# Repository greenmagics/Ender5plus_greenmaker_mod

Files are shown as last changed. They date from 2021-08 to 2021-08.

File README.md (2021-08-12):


# Ender5plus GreenMaker MOD by GreenMagic
Oto mój projekt drukarki 3D opartej na Ender 5 plus.
Lista zmian względem oryginalnej konstrukcji:

  - Kółka Vslot zostały zamienione na prowadnice liniowe MGN12 (2x oś X, 2x oś Y)
  - Bowden zmieniono na BMG direct drive
  - Hotend V6
  - Nadmuch wentylatorem 5015
  - Dodano napinacze pasków
  - Cała karetka osi X aluminiowa
 
Najważniejszą zmianą z tych wszystkich jest wykorzystanie prowadnic liniowych MGN12, które zapewniają sztywność przy dużych prędkościach.
Z powodzeniem od roku używam poprzedniej wersji tego projektu, która wykorzystywała jedną prowadnicę liniową na osi X.
Niewielki luz, który jest potrzebny do poprawnej pracy wózka liniowego powodował wibracje stosunkowo ciężkiego napędu direct i drgania.
Zastosowanie dwóch prowadnic liniowych z obu stron profila 2020 wraz z systemem kasowania luzu rozwiązuje ten problem.




# Oto schemat części, które zostały zmienione względem oryginału:
(Nie licząc napędu osi Y, który został niezmieniony oraz profilu Vslot osi X)



# TODO:
  * Zaprojektować dyszę nadmuchu chłodzącego wydruk (tutaj bardzo bym prosił o pomoc :) )
  * Dodać mocowania końców paska do karetki
  * Dodać model 3D dystansu 5mm pomiędzy BLtouch a jego mocowanie
  * Dodać listę części
  * Dodać rysunki techniczne elementów do wycięcia z aluminium
  * Dodać pliki STL modeli do druku
  * Zaokrąglić krawędzie modeli

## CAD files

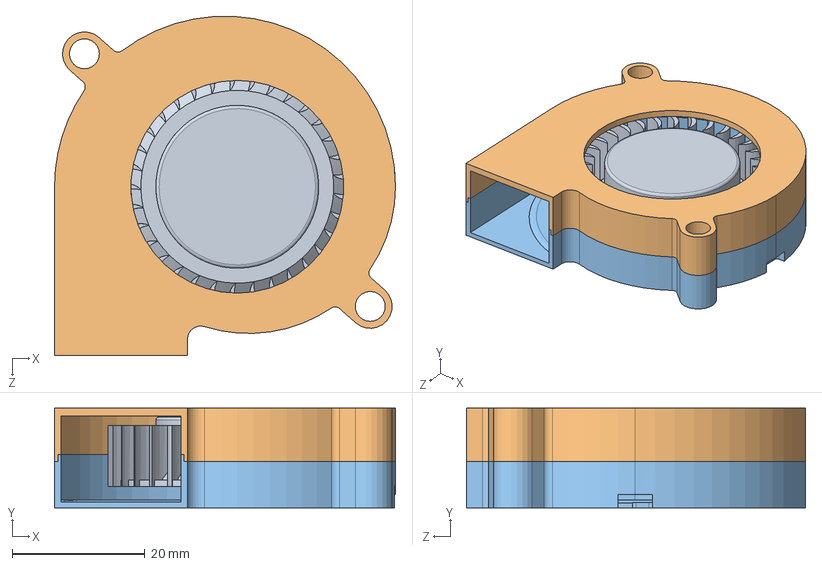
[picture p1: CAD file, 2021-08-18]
czesci_dodane/direct/Radial-Cooling-Fan-5015-DC12V v3.SLDASM
51.3 x 15.0 x 51.0 mm
turbine.stp
top.stp
bottom.stp

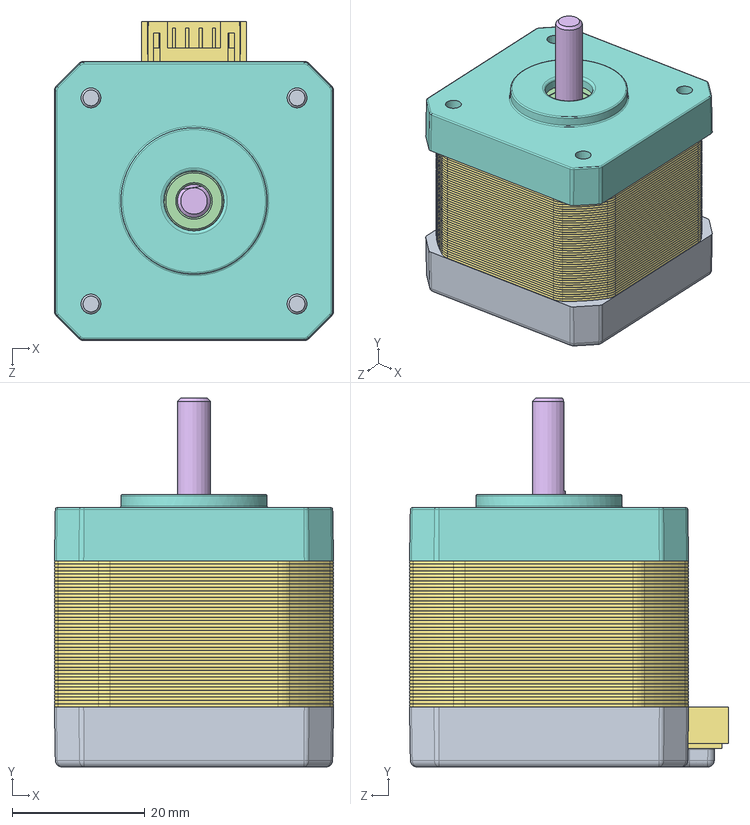
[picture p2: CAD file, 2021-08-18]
czesci_dodane/nema17/Nema17.SLDASM
42.0 x 55.5 x 48.0 mm
Bottom_cap
Protective_film_bottom
Bearing_spring
Bearing x 2
Thick_washer x 2
Rotor
Stator
Top_cap
Screw x 4

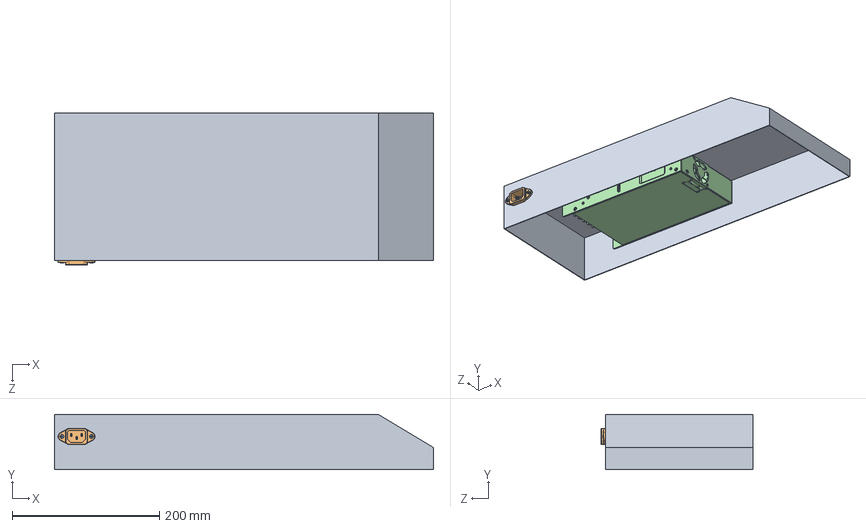
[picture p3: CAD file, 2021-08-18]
parts/electronics/electronics box assembly.SLDASM
515.0 x 75.0 x 206.2 mm
electronics box
iec320_703W-00_04
socket countersunk head screw_am x 2
rsp-500-24

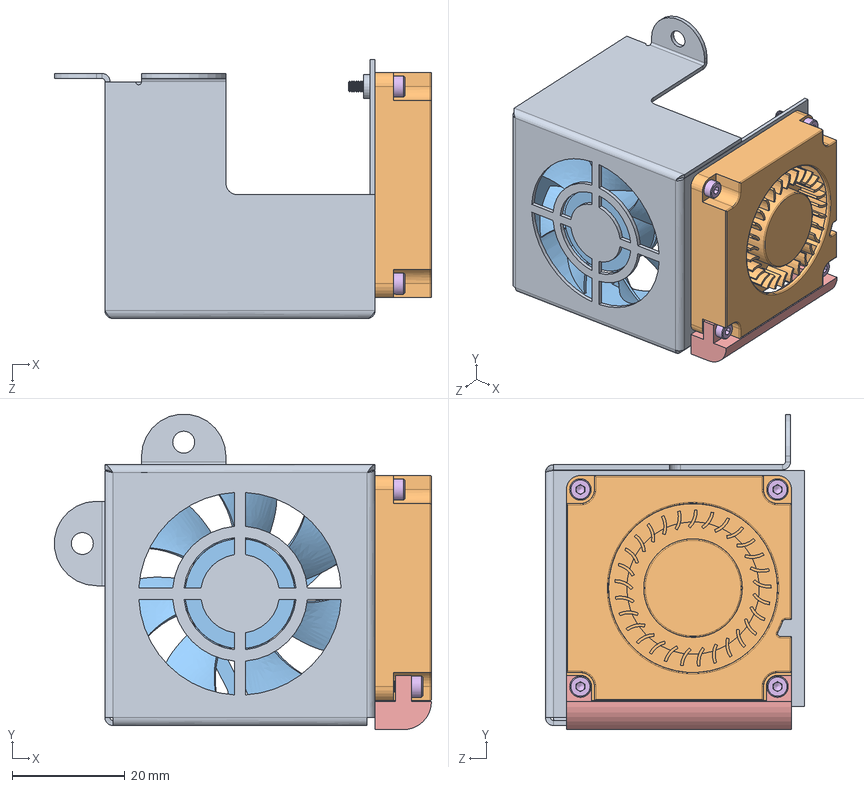
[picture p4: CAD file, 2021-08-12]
parts/hot-end/fan-shroud-assem.SLDASM
66.9 x 56.0 x 46.0 mm
fan-shroud
part-cooling-fan
hot-end-fan
bhcs-M3 x 4
part-fan-duct
shcs-M2 x 4

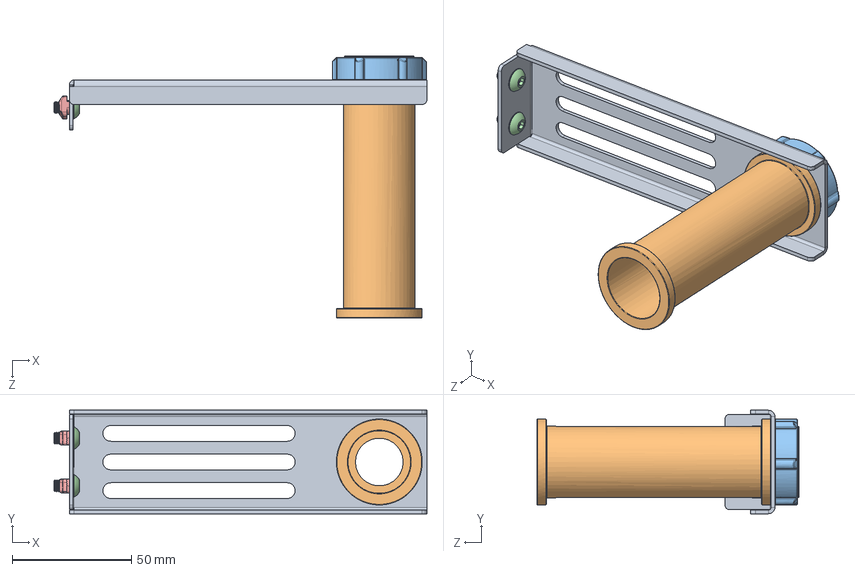
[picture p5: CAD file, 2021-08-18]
parts/spool-holder/spool-holder-assem.SLDASM
156.4 x 43.4 x 110.0 mm
spool-bracket
spool-spindle
spool-spindle-ring
bhcs-M5 x 2
t-slot-nut x 2

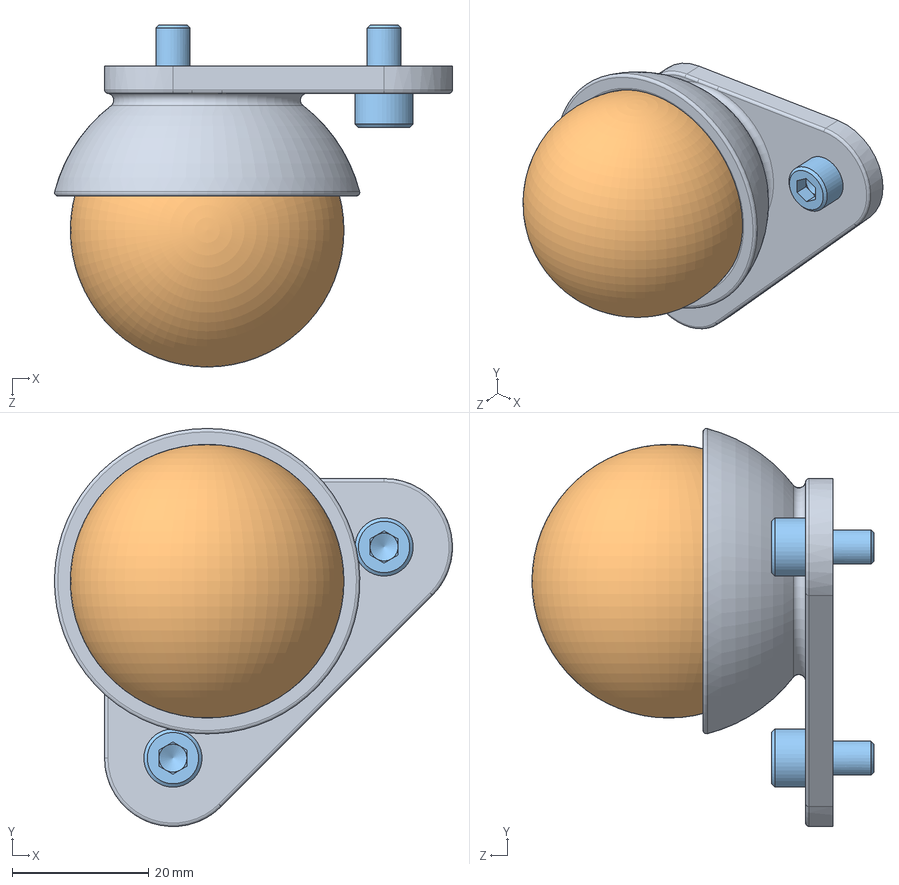
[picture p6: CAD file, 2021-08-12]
squash ball feet/squash ball foot assembly.SLDASM
58.2 x 58.2 x 50.0 mm
squash ball foot v1
squash ball
socket head cap screw_am x 2

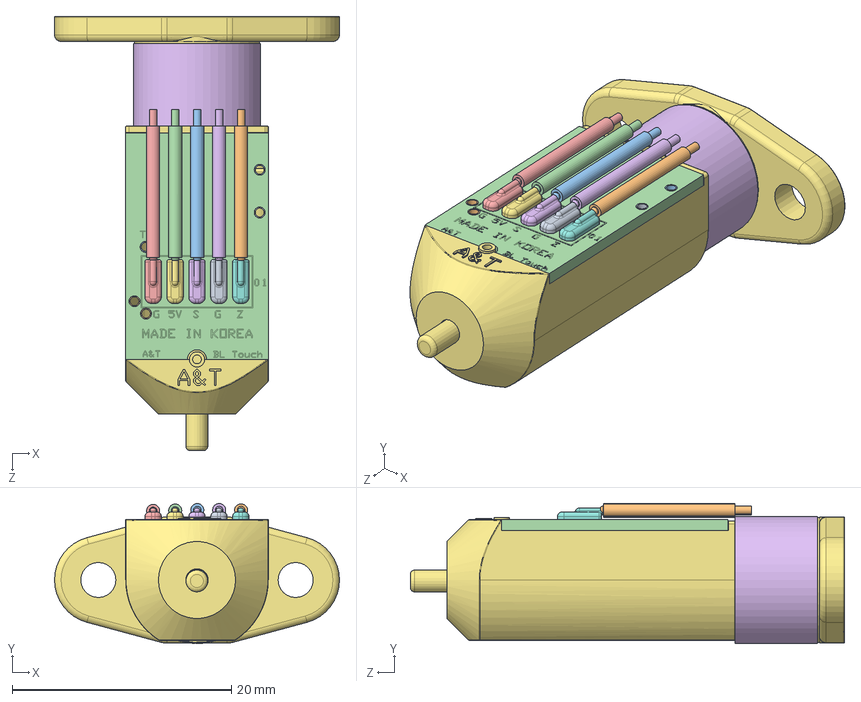
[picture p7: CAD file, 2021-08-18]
czesci_dodane/direct/Antclabs BLTouch sensor v2.SLDASM
26.0 x 12.8 x 39.6 mm
Component28.stp
Component25.stp
Component20.stp
Board (1).stp
yellow.stp
brown.stp
red.stp
white.stp
black.stp
Component30.stp
Component31.stp
LED smd v1.stp
part5 v1.stp
Diode smd v1.stp
part6 v1.stp
part2 v1.stp
part3 v1.stp
part6 v1 (1).stp
part5 v1 (1).stp
part5 v1 (2).stp
part5 v1 (2) (1).stp
Classic Kapton Tape.stp
Shell (1).stp
Component45.stp
Adjustment Screw (1).stp
Z.stp
S.stp
VCC 5V.stp
GND.stp
Z GND.stp
Probe.stp

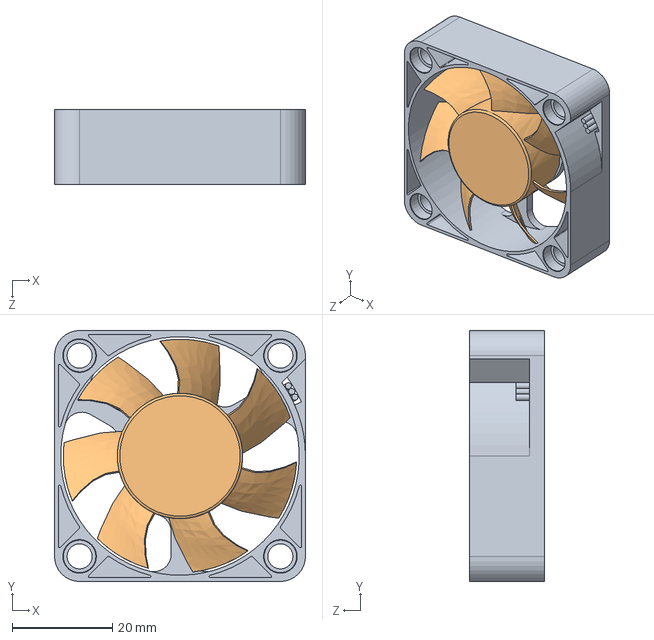
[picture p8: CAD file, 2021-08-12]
heatbreak and part cooling fan/Gelid Silent 5.SLDASM
50.0 x 50.0 x 15.0 mm
Gelid Silent 5 frame
Gelid Silent 5 rotor

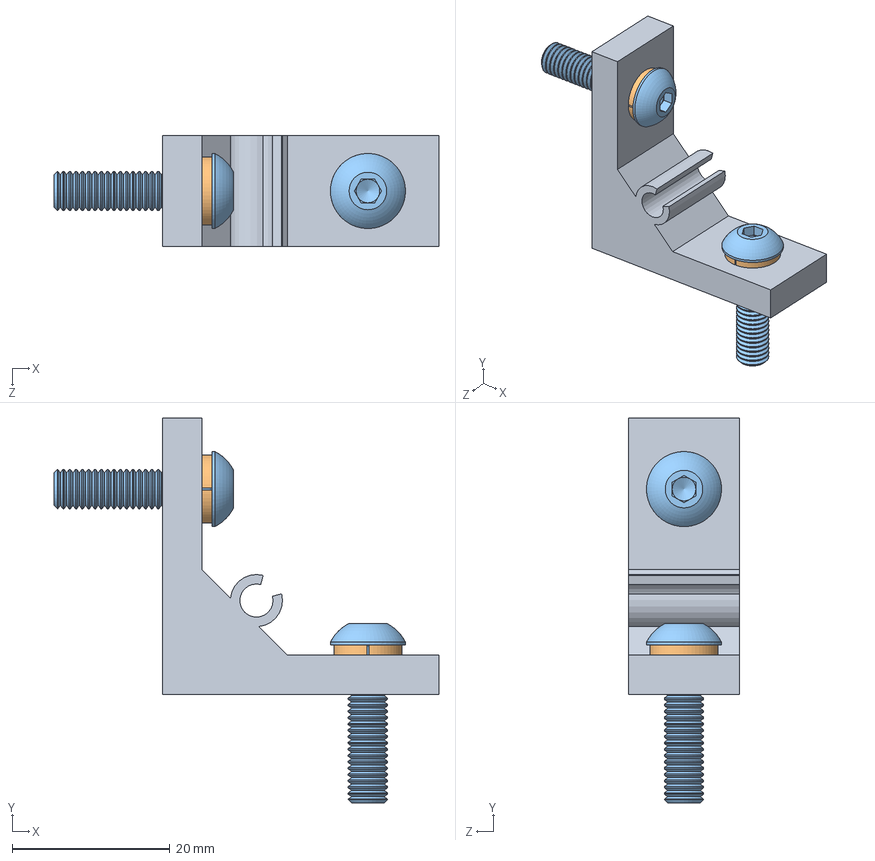
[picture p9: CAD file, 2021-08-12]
parts/corner-bracket-assem.SLDASM
48.8 x 48.8 x 14.0 mm
corner-bracket
lock-washer x 2
bhcs-M5 x 2

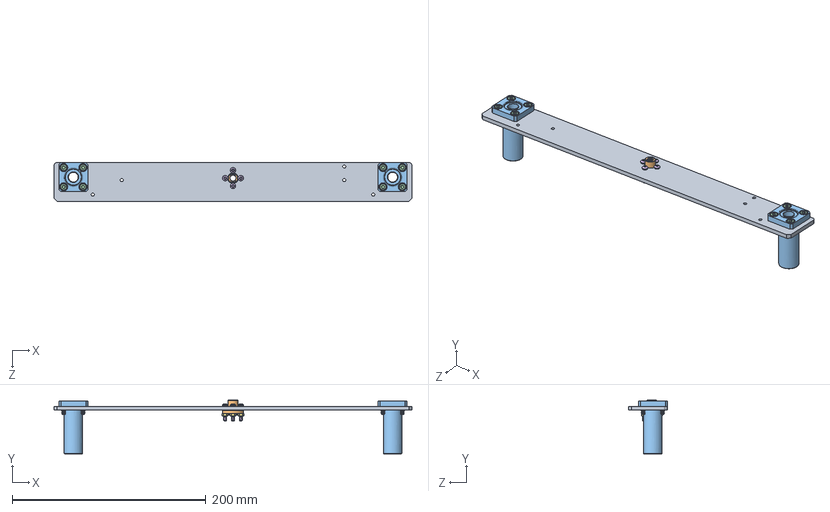
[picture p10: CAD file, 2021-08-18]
parts/z-axis-drive-assem/z-axis-bearing-plate-assem.SLDASM
370.0 x 55.8 x 40.0 mm
z-axis-bearing-plate
lead-screw-nut
flanged-bearing-10mm x 2
shcs-M4 x 8
lock-washer x 4
bhcs-M3 x 4
hex-nut-3mm x 4

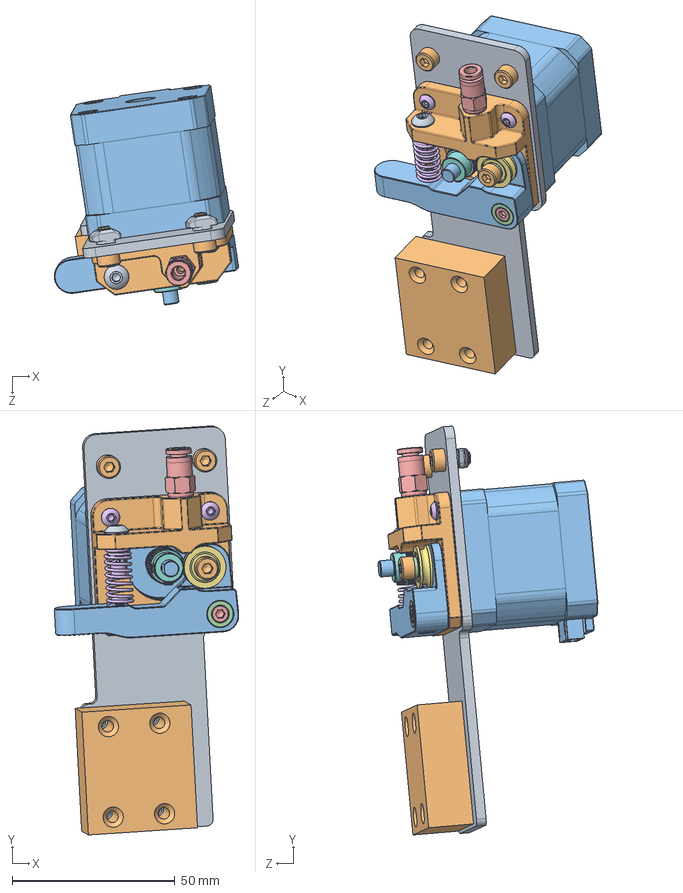
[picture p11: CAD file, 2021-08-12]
parts/extruder/extruder-assem.SLDASM
56.7 x 125.8 x 67.6 mm
extruder-mount-plate
extruder-feed-bracket
extruder-feed-arm
extruder-pivot-bushing
hose-fitting-4x6mm
extruder-spring-bushing
extruder-pulley
extruder-gear
t-slot-nut x 2
shcs-M4 x 3
stepper-motor
lock-washer
shcs-M3
bhcs-M3 x 3
set-screw-M3 x 2
fhsc-M3
bhcs-M4
filament sensor

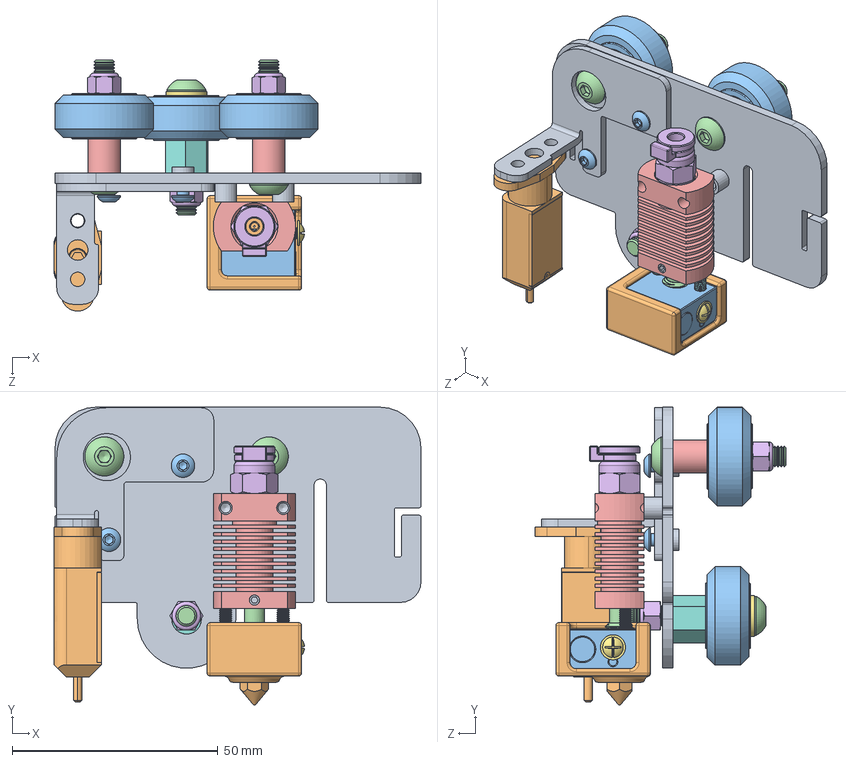
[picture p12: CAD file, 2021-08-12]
parts/x-axis-assem/hot-end-carriage-assem.SLDASM
89.2 x 72.4 x 61.1 mm
hot-end-carriage-plate
nozzle-04
hot-end-heater-block
heat-break
heat-sink
hose-fitting-4x10mm
bh-screw-flanged-M3
fhsc-M3 x 2
set-screw-M3 x 2
hot-end-boot
wheel x 3
bhcs-M5 x 3
wheel-spacer x 2
locknut-M4 x 3
flat-washer
eccentric-nut
bltouch bracket
BLTouch.step
socket button head cap screw_am x 2

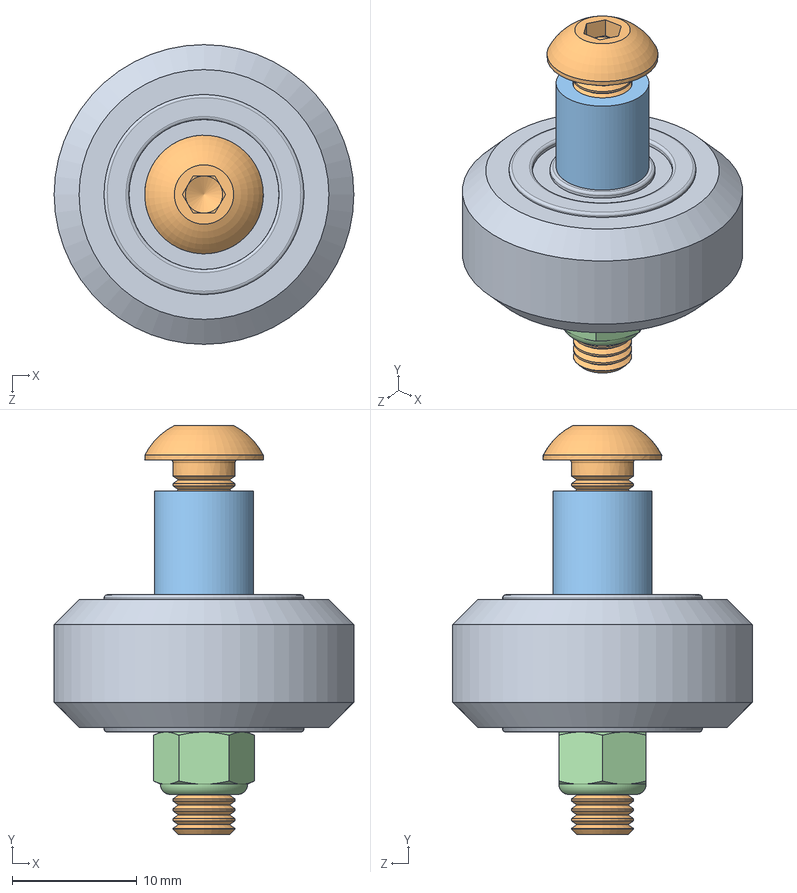
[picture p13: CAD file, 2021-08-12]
parts/x-axis-assem/wheel-assem/wheel-assem-spacer_hotend.SLDASM
24.0 x 32.8 x 24.0 mm
wheel
bhcs-M5
wheel-spacer
locknut-M4

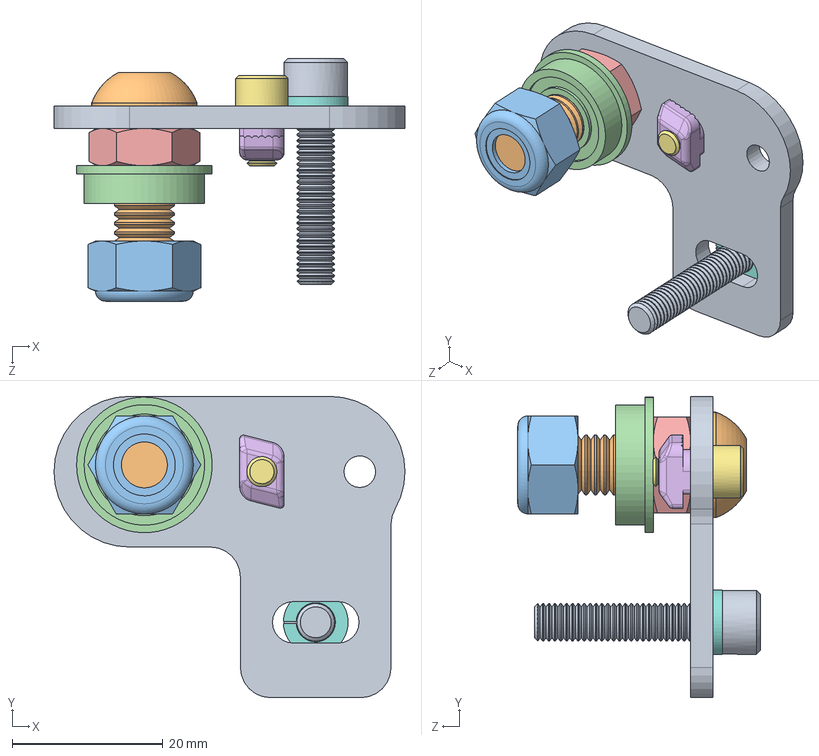
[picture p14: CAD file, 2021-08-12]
parts/Y-AXIS-ASSEM/front-corner-pulley-assem.SLDASM
46.6 x 40.0 x 32.2 mm
front-pulley-bracket
bhcs-M8
locknut-M8
pulley-half
hex-nut-8mm
t-slot-nut
shcs-M4
lock-washer
shcs-M5

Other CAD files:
parts/z-axis-drive-assem/z-axis-assem.SLDASM
heatbreak and part cooling fan/heatbreak fan mount assembly.SLDASM
parts/frame/frame assembly.SLDASM
parts/Y-AXIS-ASSEM/rear-pulley-assem.SLDASM
czesci_dodane/GT2/Belt Tensioner Type B.STEP
czesci_dodane/GT2/Configurable GT2 Timing Pulleys Lined Up.SLDASM
czesci_dodane/GT2/GT2 - 20T_Tension Pulley Without Teeth+603ZZ _dzino.SLDPRT
czesci_dodane/GT2/GT2 Timing Pulley, Configurable.SLDASM
czesci_dodane/GT2/GT2_20T-sh8.SLDPRT
czesci_dodane/GT2/GT2_40T_5_6.SLDPRT
czesci_dodane/GT2/GT2_40T_8_6.SLDPRT
czesci_dodane/GT2/mocowanie_rolki.SLDPRT
czesci_dodane/GT2/pasek_gt2.SLDPRT
czesci_dodane/direct/17HM08-1204S Nema17 Pancake 21mm.step
czesci_dodane/direct/E3D V6 Heaterblock v4.SLDPRT
czesci_dodane/direct/E3D V6 Lite v8.SLDPRT
czesci_dodane/direct/Kit Extrusora - Hotend E3D-V6_175-300.stp
czesci_dodane/direct/Nozzle V6 v3.SLDPRT
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

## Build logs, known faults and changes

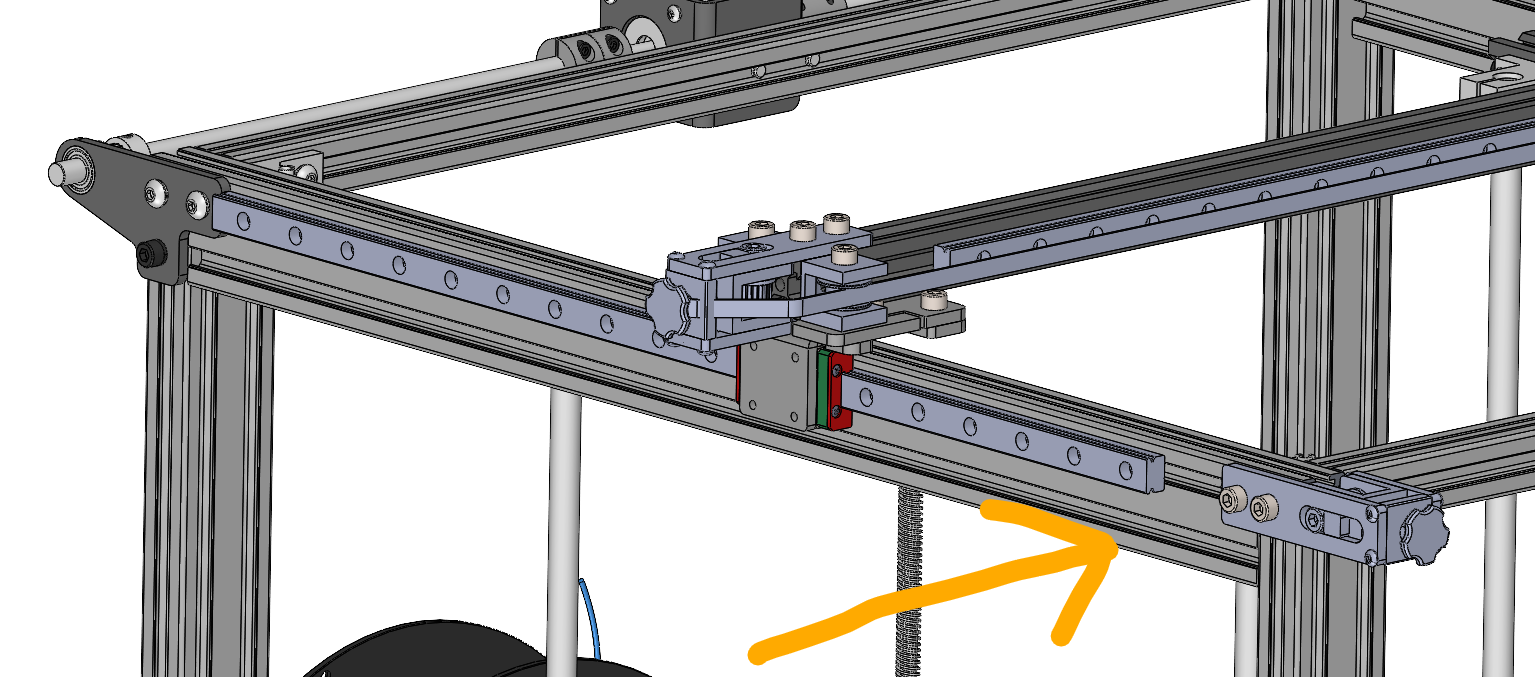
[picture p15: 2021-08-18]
zdj/issue_CBDesignS.png

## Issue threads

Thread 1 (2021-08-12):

Front Y belt tensioners will not work

CBDesignS, 2021-08-12:
looking at your design, It looks quite impressive but, there is always a but. Your front Y axis belt tensioners will not work until they are rotated 90 degree and the linear rail shortened.

greenmagics, 2021-08-18:
Thank you for your vigilance!
Of course you are right, I have out of habit added MGN12 profiles with a length of 500mm when they should be 450mm long.
I turned the Y-axis belt tensioners because, as you saw, the previous arrangement was wrong.

Best regards and I encourage you to make further comments and tips;)
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

Closed 2021-08-18.

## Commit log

2021-08-12 Dodano wersję V1.0
    Podstawowa wersja plików z dnia 12.08.2021 godzina 12:18
    [17HM08-1204S Nema17 Pancake 21mm.step, Antclabs BLTouch sensor v2.SLDASM, BLTouch.STEP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]
2021-08-18 Zmiana długości profili MGN12 z 500mm na 450mm, obrócenie napinaczy osi Y.
    Naprawiono błąd zaułważony przez CBDesignS.
    [Antclabs BLTouch sensor v2.SLDASM, Nema17.SLDASM, Radial-Cooling-Fan-5015-DC12V v3.SLDASM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]
